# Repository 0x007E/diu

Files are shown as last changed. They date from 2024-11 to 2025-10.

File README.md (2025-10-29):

   

# `DIU` - Digital (Analog) Clock (Digitaluhr)



The `DIU` project is based on a pcb with an [ATtiny1606](#additional-information) a RTC [MCP7940](#additional-information) a USB/UART bridge [FT232RL](#additional-information) and a set of [74HC595](#additional-information) shift register. It can be used to display time and date on 84 `LEDs` that are mounted in 3 circles to the top pcb. The clock itself can be setup over UART and a terminal software ([e.g. TeraTerm](#additional-information)).

| Experience | Level |
|:---|:-----:|
| Soldering | ?% |
| Mechanical  | ?% |
| Software | ?% |

# Downloads

| Type | File | Description |
|:---:|:---:|:---|
| Schematic | [pdf](https://github.com/0x007E/diu/releases/latest/download/schematic.pdf) / [cadlab](https://cadlab.io/project/28616/main/files) | Schematic files |
| Board | [pdf](https://github.com/0x007E/diu/releases/latest/download/pcb.pdf) / [cadlab](https://cadlab.io/project/28616/main/files) | Board file |
| Drill | [pdf](https://github.com/0x007E/diu/releases/latest/download/drill.pdf) | Drill file |
| PCB | [zip](https://github.com/0x007E/diu/releases/latest/download/kicad.zip) / [tar](https://github.com/0x007E/diu/releases/latest/download/kicad.tar.gz) | KiCAD/Gerber/BoM/Drill files |
| Mechanical | [zip](https://github.com/0x007E/diu/releases/latest/download/freecad.zip) / [tar](https://github.com/0x007E/diu/releases/latest/download/freecad.tar.gz) | FreeCAD/Housing and PCB (STEP) files |
| Firmware | [zip](https://github.com/0x007E/diu/releases/latest/download/firmware.zip) / [tar](https://github.com/0x007E/diu/releases/latest/download/firmware.tar.gz) | Firmware for ATtiny1606 |
| Test-Firmware | [zip](https://github.com/0x007E/diu/releases/latest/download/test-firmware.zip) / [tar](https://github.com/0x007E/diu/releases/latest/download/test-firmware.tar.gz) | Test-Firmware for ATtiny1606 |

# Hardware

There are two parts of the hardware. The pcb and the housing of the `DIU`. The pcb is created with [KiCAD](#additional-information) and the housing with [FreeCAD](#additional-information). The software is programmed with [Microchip (Atmel) Studio](#additional-information). All files are built with `github actions` so that they are ready for a production environment. The housing is printed with a 3D-printer (`Dremel 3D40`).

## PCB

The circuit board is populated on both sides (Top, Bottom). The best way for soldering the `SMD` components is within a vapor phase soldering system and for the `THT` components with a standard soldering system. After placing and soldering the top parts, the board has to be cut off in the middle (white edge).

### Top Layer

Top Layer

### Bottom Layer

Bottom Layer

## Mechanical

The housing has a tolerance of `0.2mm` on each side of the case. So the pcb should fit perfectly in the housing. The tolerance can be modified with `FreeCAD` in the `Parameter` Spreadsheet. The corners of the circuit board need to be sanded a little.

### Assembled

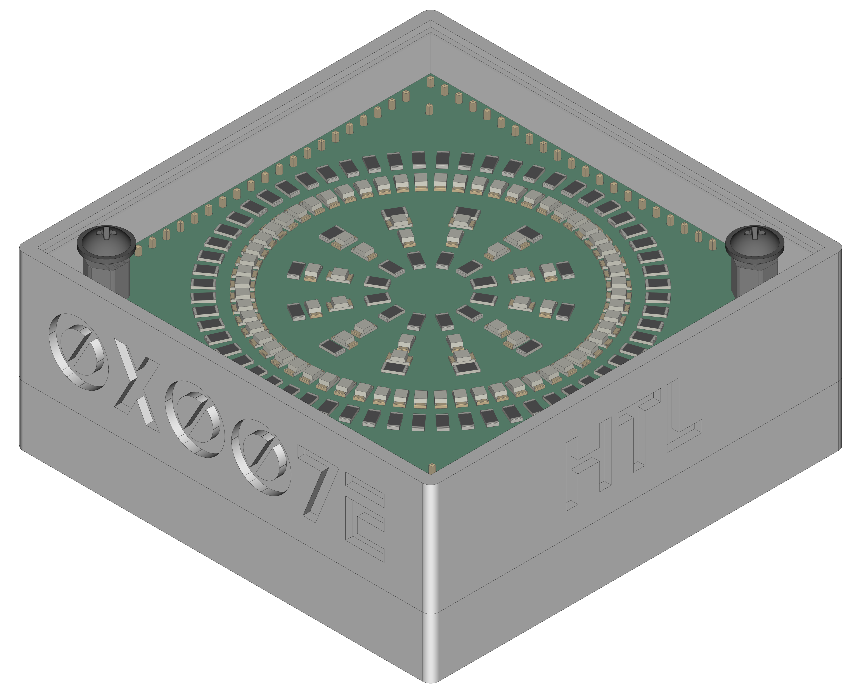
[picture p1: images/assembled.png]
Assembled


#### Exploded

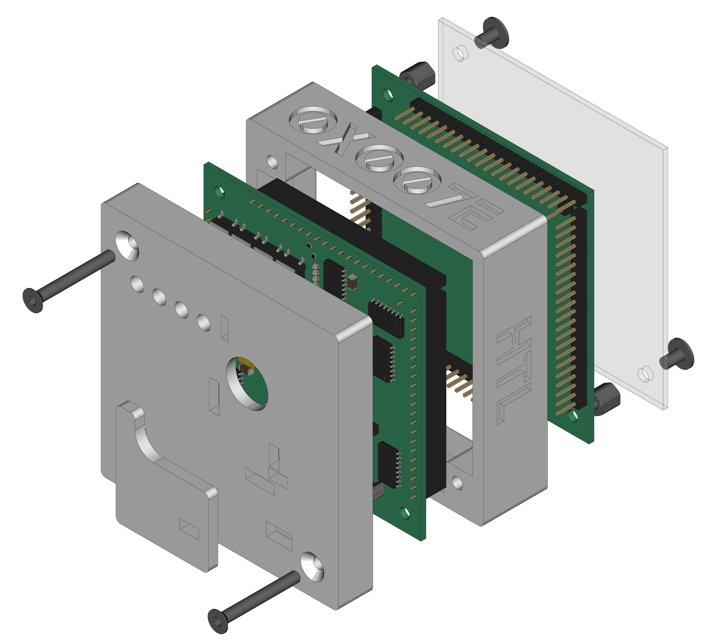
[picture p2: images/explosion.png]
Exploded


# Programming/Setup

The `DIU` can be powerd with `5V` from USB or an external source through connector `J1`. Over [UPDI](#additional-information) (`J3`) the `DIU` can be programmed with `avr-dude` or an [Microchip (Atmel) ICE](#additional-information) adapter. To setup the `DIU` it can be connected over USB to a computer and  configured with a terminal (e.g. [TeraTerm](#additional-information)) software. The firmware for the clock can be downloaded from the [download section](#downloads).

## FUSES

| Register  | Value  |
|:---:|:---:|
| `WDTCFG`  | `0x00` |
| `BODCFG`  | `0x00` |
| `OSCCFG`  | `0x02` |
| `TCD0CFG` | `0x00` |
| `SYSCFG0` | `0xF5` |
| `SYSCFG1` | `0x00` |
| `APPEND`  | `0x00` |
| `BOOTEND` | `0x00` |

> To setup `RESET` (`PA0`) it is necessary to change the `SYSCFG0`-FUSE of the `ATtiny1606`. WARNING: To reset the `PA0` pin to `UPDI` mode a `12V` impulse is necessary to program the FUSES again.

# Firmware

The firmware of the `DIU` project can be downloaded and modified with [Microchip Studio](#additional-information). The software can be found in the [`./firmware`](./firmware/) directory and is splitted into different libraries. They can be found in the [./firmware/lib`](./firmware/lib/) folder. Feel free to modify the firmware to your own needings.

## Dataflow diagram

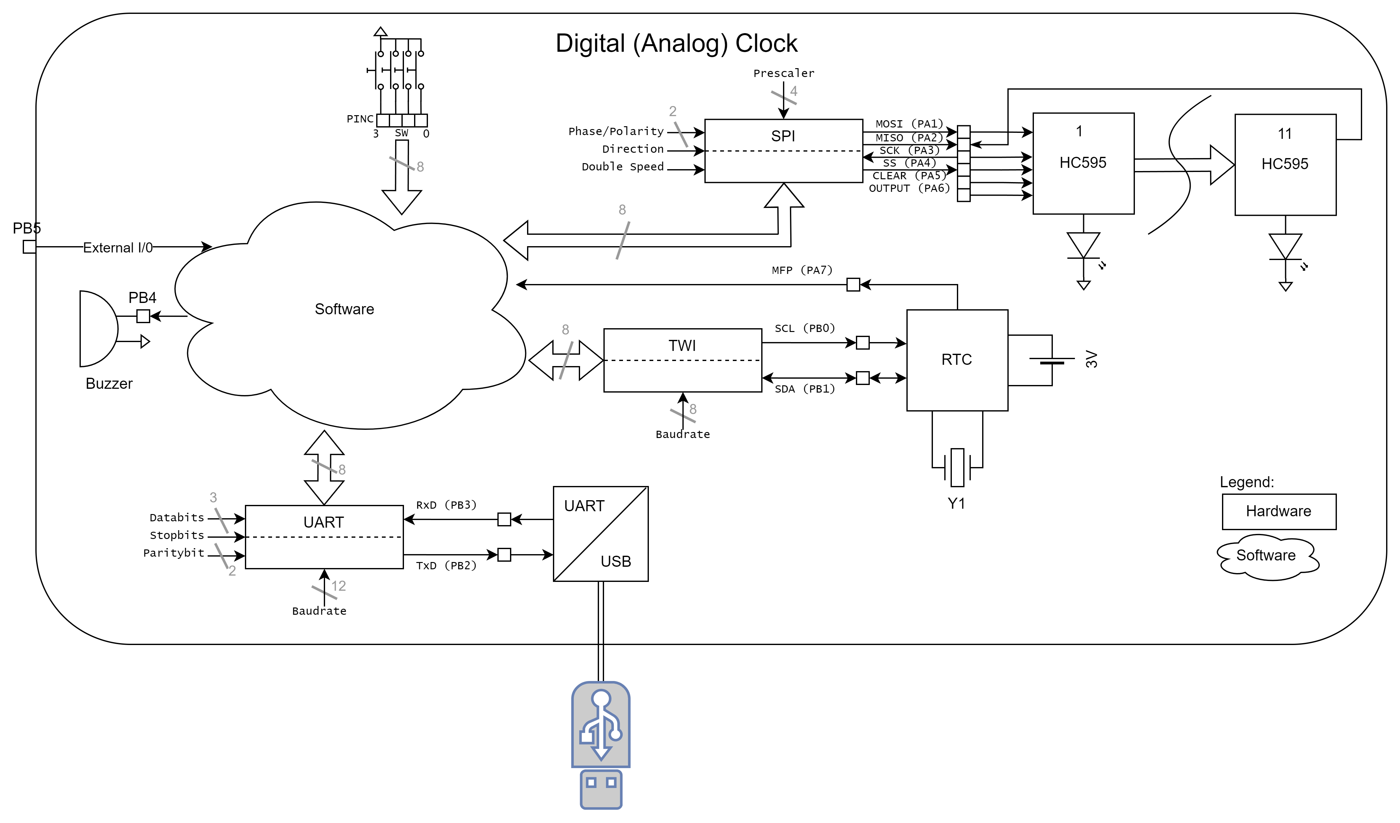
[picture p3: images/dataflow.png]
Dataflow


## UART Setup

To configure the `DIU` through UART (USB/UART bridge) a connection over USB to a computer and a terminal software (e.g. [Teraterm](#additional-information) is necessary. To start the setup the following settings need to be configured in the terminal. Then hit a key during init process in the terminal.

| Name | Value  |
|:---:|:---:|
| PORT | COM? |
| BAUD | 9600 |
| DATABITS  | 8 |
| PARITY | NONE |
| STOPBITS  | 1 |
| FLOWCTRL  | NONE |

### Connection setup

``` bash
# +--------------------------------------------------+
# |       ~------------------+                       |      +---------------------+
# |      ~  ATTINY 1606      |                       |      |                     |
# |     ~                  +-+-+                     |      | +-----------------+ |
# |    ~               VCC | 1 |          +----------+      | | TeraTerm        | |
# |      ~             PB0 | 2 |          |   U  +---+---+  | | ~~~~~~~~        | |
# |        ~           PB1 | 3 |          |   S  |  USB  |--+ | ~~~~~           | |
# |         ~    (TxD) PB2 | 4 +-----+    |   B  +---+---+  | | ~~~~~~~~~~~~    | |
# |        ~     (RxD) PB3 | 5 +--+  |    |   /      |      | |                 | |
# |       ~            GND | 6 |  |  |    |   U      |      | +-----------------+ |
# |     ~                  +-+-+  |  |    |   A      |      |                     |
# |    ~~~~~-----------------+    |  |  +-+-+ R      |      | Computer            |
# |                               |  +--+TxD| T      |      |                     |
# |  DDD   IIIIII UU  UU          +-----+RxD| +------+      +---------------------+
# |  D  D    II   UU  UU                +-+-+ |5V/3V3|
# |  D  D    II   UU  UU                  +----+-----+
# |  DDD   IIIIII  UUUU                              |
# +--------------------------------------------------+
```

### Enter configuration menu

To enter into the configuration mode it is necessary to press a `key` during startup.

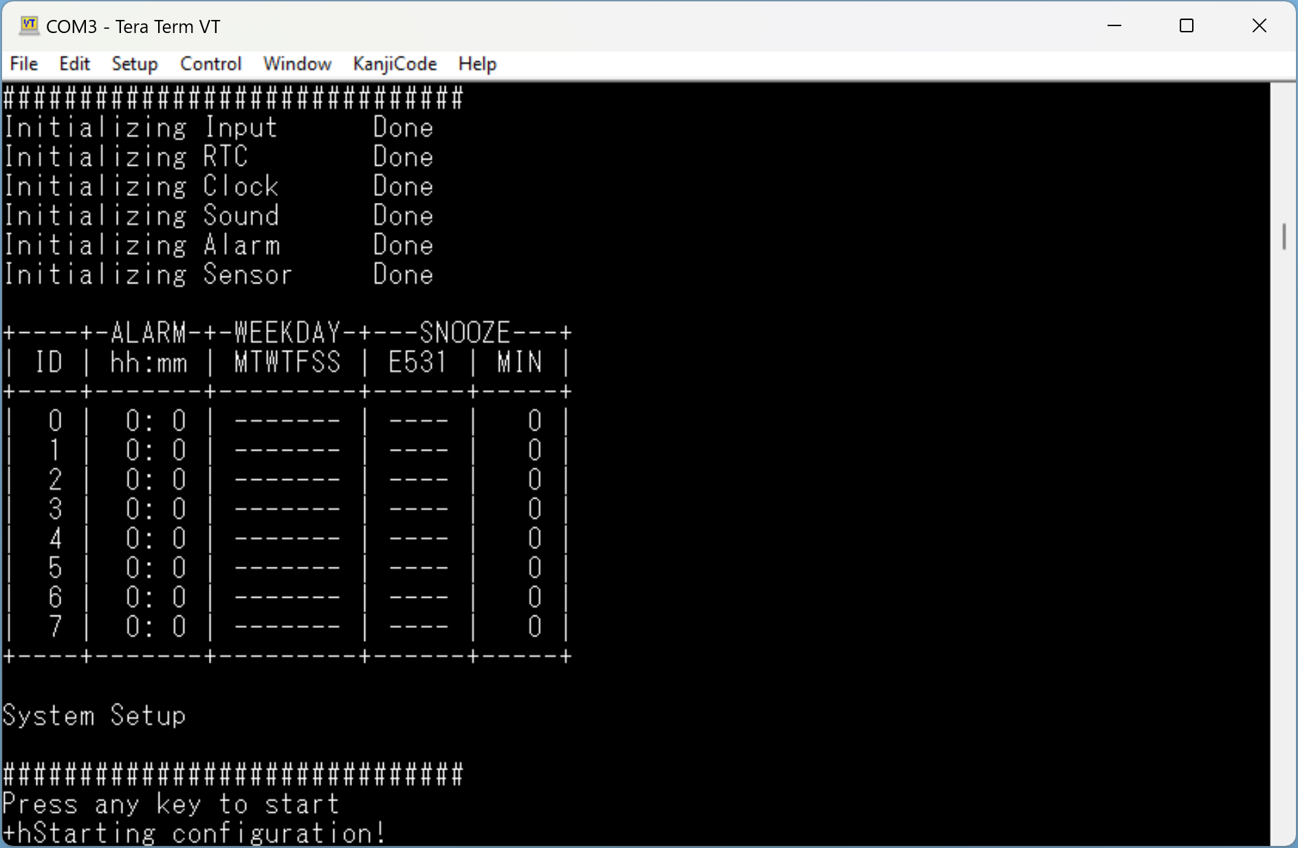
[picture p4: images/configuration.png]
Press a Key


The configuration starts and a menu to setup the `DIU` appears.

``` bash
# +------------------------------------------------+
# | System Configuration                           |
# +------------------------------------------------+
# | [1] Time and Date                              |
# | [2] Alarm                                      |
# | [3] Alarm Tone                                 |
# | [4] LED Intensity                              |
# | [5] Oscillator                                 |
# | [d] Discharge changes                          |
# | [q] Exit configuration                         |
# +------------------------------------------------+
# Input:
```

## TWI-Configuration

The `DIU` itself uses a `RTC` ([MCP7940](#additional-information)) with a power reserve (`battery`) to store the time. The `firmware` is connecte to the `RTC` over `TWI`. The twi configuration is stored in [`twi.h`](./firmware/lib/twi/twi.h) and the rtc configuration in [`mcp7940.h`](./firmware/lib/rtc/mcp7940.h) file.

### Connection between `ATtiny1606` and `MCP7940`

``` bash
# +----------------------------------------------------------------------------------------------------+
# |                               VCC VCC                                                              |
# |                                ^   ^                                                               |
# |                                |   |                                                               |
# |                             R +++ +++ R                                                            |
# |                             9 | | | | 1                                                            |
# |       ~------------------+  9 | | | | 0                                J                           |
# |      ~  ATTINY 1606      |    +++ +++ 0    +---------------------+     1    ~~~~~~                 |
# |     ~                  +-+-+   |   |     +-+-+                 +-+-+   8   ~  3   ~                |
# |    ~               VCC | X +---|---|-----+ 8 | VCC         BAT | 3 +--(X)-+   V    +------| GND    |
# |    ~         (SCL) PB0 | 0 +---+---|-----+ 6 | SCL             +-+-+       ~  0   ~                |
# |     ~        (SDA) PB1 | 1 +-------+-----+ 5 | SDA      M        |          ~~~~~~   C30           |
# |       ~            PB2 | 2 |             +-+-+          C      +-+-+                 ||            |
# |        ~           PB3 | 3 |           +-+ 5 | MFP      P   X! | 1 +----------+------||----| GND   |
# |         ~          PB4 | 4 |          /  +-+-+          7      +-+-+         ---     ||            |
# |         ~          PB5 | 5 |         /     |            9        |         +-----+                 |
# |        ~           PB6 | 6 |        /    +-+-+          4        |         |  Y1 | 32.768 kHz      |
# |       ~            GND | X +-------/-----+ 4 |          0        |         +-----+                 |
# |      ~                 +-+-+      /      +-+-+                 +-+-+         ---     ||            |
# |     ~                    |       /         |                X2 | 2 +----------+------||----| GND   |
# |     ~                  +-+-+    /          |                   +-+-+                 ||            |
# |      ~                 ~   ~   /           +---------------------+                   C31           |
# |       ~                ~   ~  /                                                                    |
# |        ~           PA7 | 7 +-+             DDD   IIIIII UU  UU                                     |
# |         ~              +-+-+               D  D    II   UU  UU                                     |
# |         ~                |                 D  D    II   UU  UU                                     |
# |        ~-----------------+                 DDD   IIIIII  UUUU                                      |
# +----------------------------------------------------------------------------------------------------+
```

### TWI Parameter

To read and save parameters in th `RTC` over `TWI` the bus is configured with the following setup:

| Parameter | Value | Description |
|:---|:---:|:---|
| Speed | 400kHz  | Bus clock speed |

> Detail can be found [here](https://en.wikipedia.org/wiki/I%C2%B2C)

### RTC-Commands

``` c
             void mcp7940_init(RTC_Mode battery);
             void mcp7940_battery(RTC_Mode mode);
             void mcp7940_oscillator(RTC_Mode mode);

    unsigned char mcp7940_oscillator_value(void);
             void mcp7940_oscillator_copy(Copy_Mode mode);

       RTC_Status mcp7940_powerfail_status(void);
       RTC_Status mcp7940_oscillator_status(void);

      const char* mcp7940_weekday_string(unsigned char day);
    
    unsigned char mcp7940_hour(RTC_Data data);
    unsigned char mcp7940_minute(RTC_Data data);
    unsigned char mcp7940_second(void);

    unsigned char mcp7940_weekday(RTC_Data data);
    unsigned char mcp7940_day(RTC_Data data);
    unsigned char mcp7940_month(RTC_Data data);
    unsigned char mcp7940_year(void);
    unsigned char mcp7940_leapyear(void);

       RTC_Status mcp7940_setweekday(unsigned char weekday);
       RTC_Status mcp7940_settime(unsigned char hour, unsigned char minute, unsigned char second);
       RTC_Status mcp7940_setdate(unsigned char day, unsigned char month, unsigned char year);
       RTC_Status mcp7940_setoscillator(unsigned char trim);
```

## SPI-Configuration

The `firmware` itself is driving the LEDs over `SPI` through eleven [74HC595](#additional-information) shift registers. The spi configuration is stored in the [`clock.h`](./firmware/lib/clock/clock.h) and [`spi.h`](./firmware/lib/spi/spi.h) files.

### Connection between `ATtiny1606` and `74HC595`

``` bash
# +------------------------------------------------------------------------------------------------------+
# |                                     +----------------------------... ~ ...------------------------+  |
# |       ~------------------+         /            START(1)            ~             END(11)         |  | 
# |      ~  ATTINY 1606      |        /        +---------------+       ~         +---------------+    |  |
# |     ~                  +-+-+     /       +-+-+  74HC595  +-+-+    ~        +-+-+  74HC595  +-+-+  |  |
# |    ~               VCC | X +----/--------+ 16|    VCC    |16 |-.. ~ ....---+ 16|    VCC    |16 |  |  |
# |    ~               PA0 | 0 |   /         +---+           +-+-+     ~       +---+           +-+-+  |  |
# |     ~       (MOSI) PA1 | 1 +--/----------+ 14| SER    QH | 9 |--... ~ ...--+ 14| SER    QH | 9 +--+  |
# |       ~     (MISO) PA2 | 2 +-+           +---+           +-+-+       ~     +---+           +-+-+     |
# |        ~     (SCK) PA3 | 3 +-------------+ 11|   SRCLK   |11 |----... ~ ..-+ 11|   SRCLK   |11 |     |
# |         ~     (SS) PA4 | 4 +-------------+ 12|    RCLK   |12 |----... ~ ..-+ 12|    RCLK   |12 |     |
# |         ~  (CLEAR) PA5 | 5 +-------------+ 10|   SRCLR   |10 |---... ~ ...-+ 10|   SRCLR   |10 |     |
# |        ~  (OUTPUT) PA6 | 6 +-------------+ 13|     OE    |13 |--... ~ ...--+ 13|     OE    |13 |     |
# |       ~            GND | X +-------------+ 8 |    GND    | 8 |-... ~ ...---+ 8 |    GND    | 8 |     |
# |     ~                  +-+-+             +-+-+           +-+-+    ~        +-+-+           +-+-+     |
# |    ~~~~~-----------------+                 +--+~~~~~~~~~+--+      ~          +--+~~~~~~~~~+--+       |
# |                                               |         |          ~            |         |          |
# |  DDD   IIIIII UU  UU                         ---  LED  ---          ~          ---  LED  ---         |   
# |  D  D    II   UU  UU                         \ /       \ /           ~         \ /       \ /         |
# |  D  D    II   UU  UU                          |         |             ~         |         |          |
# |  DDD   IIIIII  UUUU                           |         |             ~         |         |          |
# +------------------------------------------------------------------------------------------------------+
```

### SPI Parameter

To control the LEDs through the shift registers over `SPI` the bus is configured with the following setup:

| Parameter | Value | Description |
|:---|:---:|:---|
| Clock | F_CPU/4 | Bus clock speed is system speed divied by 4 |
| Direction | MSB | MSB needs to be transmitted first |
| Polarity  | Rising  | Polarity of clock is rising `_/` |
| Phase | Rising  | Data is valid when clock is rising `_/` |

> Detail can be found [here](https://de.wikipedia.org/wiki/Serial_Peripheral_Interface)

### SPI Frame

``` bash

# SPI display transmission
# _                                                SS                                                   _
#  \__________________________________________________~~~______________________________________________/
#                                                 SCK   
#     __    __    __    __    __    __    __    __       __    __    __    __    __    __    __    __    
# ___/1 \__/2 \__/3 \__/4 \__/5 \__/6 \__/7 \__/8 \__~~~/81\__/82\__/83\__/84\__/85\__/86\__/87\__/88\___
#                                                 MOSI
#    __    __    __    __    __    __    __    __       __    __    __    __    __    __    __    __
# __/H \__/O \__/U \__/R \__/  \__/  \__/  \__/  \__~~~/M \__/I \__/N \__/  \__/L3\__/L2\__/L1\__/L0\____
#   \__/  \__/  \__/  \__/  \__/  \__/  \__/  \__/     \__/  \__/  \__/  \__/  \__/  \__/  \__/  \__/
#    [7                   :                    0]    [7                   :                    0]
#
# L[3:0] ... LEDs on the backside of the pcb for signaling
```

### Clock-Commands

``` c
           void clock_init(void);
           void clock_output(CLOCK_Status status);
           void clock_clear(void);
   unsigned int clock_intensity(void);
    CLOCK_Error clock_setintensity(unsigned int intensity);
           void clock_copy_intensity(Copy_Mode mode);
    CLOCK_Error clock_settime(unsigned char hour, unsigned char minute, unsigned char second, CLOCK_Status_LED status);
    CLOCK_Error clock_setdate(unsigned char day, unsigned char month, CLOCK_Status_LED status);
           void clock_setdata(unsigned long data24, unsigned long long data60, CLOCK_Status_LED status);
           void clock_saveintensity(void);
```

# Additional Information

| Type | Link | Description |
|:---:|:---:|:---|
| ATtiny1606 | [pdf](http://ww1.microchip.com/downloads/en/DeviceDoc/ATtiny806_1606_Data_Sheet_40002029A.pdf) | ATtiny microcontroller |
| MPC7940 | [pdf](https://ww1.microchip.com/downloads/aemDocuments/documents/MPD/ProductDocuments/DataSheets/MCP7940N-Battery-Backed-I2C-RTCC-with-SRAM-20005010J.pdf) | Battery-Backed I2C Real-Time Clock/Calendar with SRAM |
| FT232RL | [pdf](https://ftdichip.com/wp-content/uploads/2020/08/DS_FT232R.pdf) | USB Full Speed to Serial UART IC, Includes Oscillator and EEPROM |
| 74HC595 | [pdf](https://www.ti.com/lit/ds/symlink/sn74hc595.pdf?) | 8-Bit Shift Registers With 3-State Output Registers |
| Atmel ICE | [pdf](https://ww1.microchip.com/downloads/en/DeviceDoc/Atmel-ICE_UserGuide.pdf) | Atmel ICE datasheet |
| UPDI | [web](https://github.com/0x007e/updi) | UPDI-Adapter with AVR-Dude |
| Microchip Studio | [web](https://www.microchip.com/en-us/tools-resources/develop/microchip-studio) | Download page for Microchip Studio |
| KiCAD | [web](https://www.kicad.org/) | KiCAD project page |
| FreeCAD | [web](https://www.freecad.org/) | FreeCAD project page |
| TeraTerm | [web](https://github.com/TeraTermProject/teraterm/releases/download/v5.3/teraterm-5.3.zip) | Terminal software for UART |

---

R. GAECHTER

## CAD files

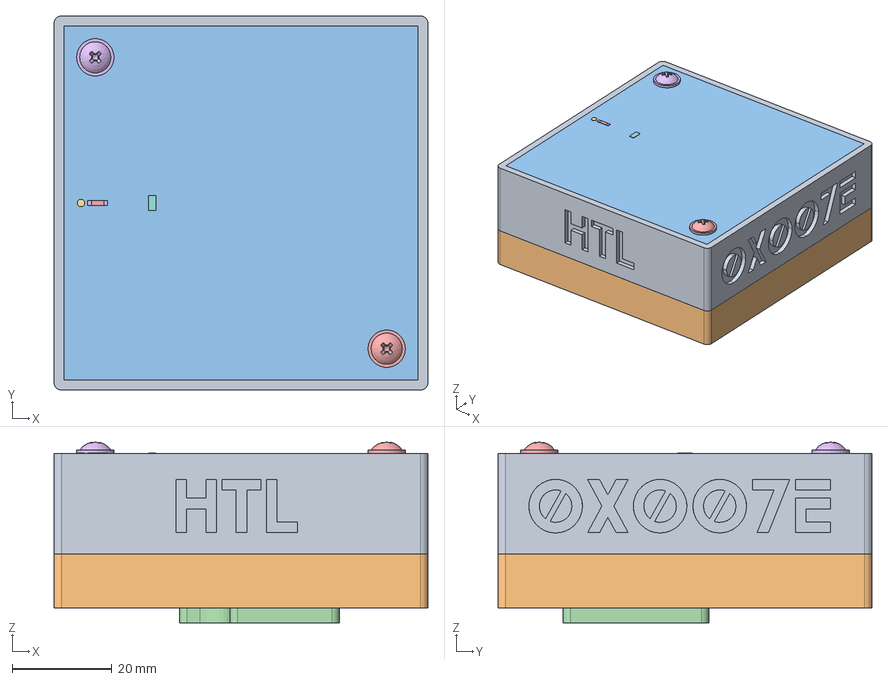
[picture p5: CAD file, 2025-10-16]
mechanical/housing.FCStd
75.0 x 75.0 x 36.2 mm
Pcb_c823
R13_R_1206_3216Metric_34334d02fc96
R44_R_1206_3216Metric_737dba1be889
R37_R_1206_3216Metric_834d129e5901
R79_R_1206_3216Metric_35fc0c29ad5f
D65_LED_1206_3216Metric_9e7b87f42873
D2_LED_1206_3216Metric_fdbedf3a3e9b
R43_R_1206_3216Metric_719967f5957d
D27_LED_1206_3216Metric_a198e4acb3d3
R38_R_1206_3216Metric_523115ea511a
D13_LED_1206_3216Metric_455e7213887b
D25_LED_1206_3216Metric_76b92dfb3f17
R21_R_1206_3216Metric_e90a38714b10
R19_R_1206_3216Metric_193c421c075a
R6_R_1206_3216Metric_35c49ca2423b
R8_R_1206_3216Metric_42ef1dca9180
D66_LED_1206_3216Metric_eba1fa753a25
R39_R_1206_3216Metric_491c422fc7de
R41_R_1206_3216Metric_edfd6f096ba8
R4_R_1206_3216Metric_de8c2cc0fb6b
R31_R_1206_3216Metric_0a769164ac2c
D45_LED_1206_3216Metric_362e80296509
R74_R_1206_3216Metric_666f53dd8cfe
D70_LED_1206_3216Metric_ddec581c3f35
D6_LED_1206_3216Metric_155b99a387b2
D53_LED_1206_3216Metric_5ce0a0b5670f
D7_LED_1206_3216Metric_7674877d52a3
R73_R_1206_3216Metric_1ad9b93e3157
R3_R_1206_3216Metric_c9d2bb2283cd
R22_R_1206_3216Metric_08c140825ab3
D68_LED_1206_3216Metric_9cb3968d07ed
D54_LED_1206_3216Metric_7693143a76bc
R55_R_1206_3216Metric_1144fcfe9ccc
R17_R_1206_3216Metric_2963d2833a7b
R7_R_1206_3216Metric_cc86824d3ca2
D71_LED_1206_3216Metric_bd39b554a851
R25_R_1206_3216Metric_359f7886d384
D23_LED_1206_3216Metric_06078b84c13d
R24_R_1206_3216Metric_ef7290cbcc05
D76_LED_1206_3216Metric_c139421844a5
R34_R_1206_3216Metric_53b750e92204
D81_LED_1206_3216Metric_de4fcd1b8e00
D39_LED_1206_3216Metric_e95fa8479d74
R60_R_1206_3216Metric_c6abe7adbdfb
D47_LED_1206_3216Metric_cf422c87c905
D55_LED_1206_3216Metric_532611b90687
D26_LED_1206_3216Metric_bbf42a41a116
D33_LED_1206_3216Metric_cf7bbe964a9d
R40_R_1206_3216Metric_b02a59e2a5f4
R62_R_1206_3216Metric_35f68ac2fdf5
R51_R_1206_3216Metric_f9cba5a0bb78
R57_R_1206_3216Metric_640c153382fb
D31_LED_1206_3216Metric_bdbaa0677122
D41_LED_1206_3216Metric_e36032ae5237
R53_R_1206_3216Metric_90ab64d636a1
D35_LED_1206_3216Metric_ba6542c84515
R28_R_1206_3216Metric_8ded0d01a810
R56_R_1206_3216Metric_063fd8314cb7
D29_LED_1206_3216Metric_22e97f871525
D22_LED_1206_3216Metric_b11cf042c014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

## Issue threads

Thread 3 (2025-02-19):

Save oscillator value for RTC in EEPROM

0x007E, 2025-02-19:
The oscillator value should be stored in the EEPROM of the MCU (ATTiny) so that it can be reloaded into the RTC after a battery change. At every startup of the RTC it should be checked an reloaded if the value between the EEPROM and the RTC differs.

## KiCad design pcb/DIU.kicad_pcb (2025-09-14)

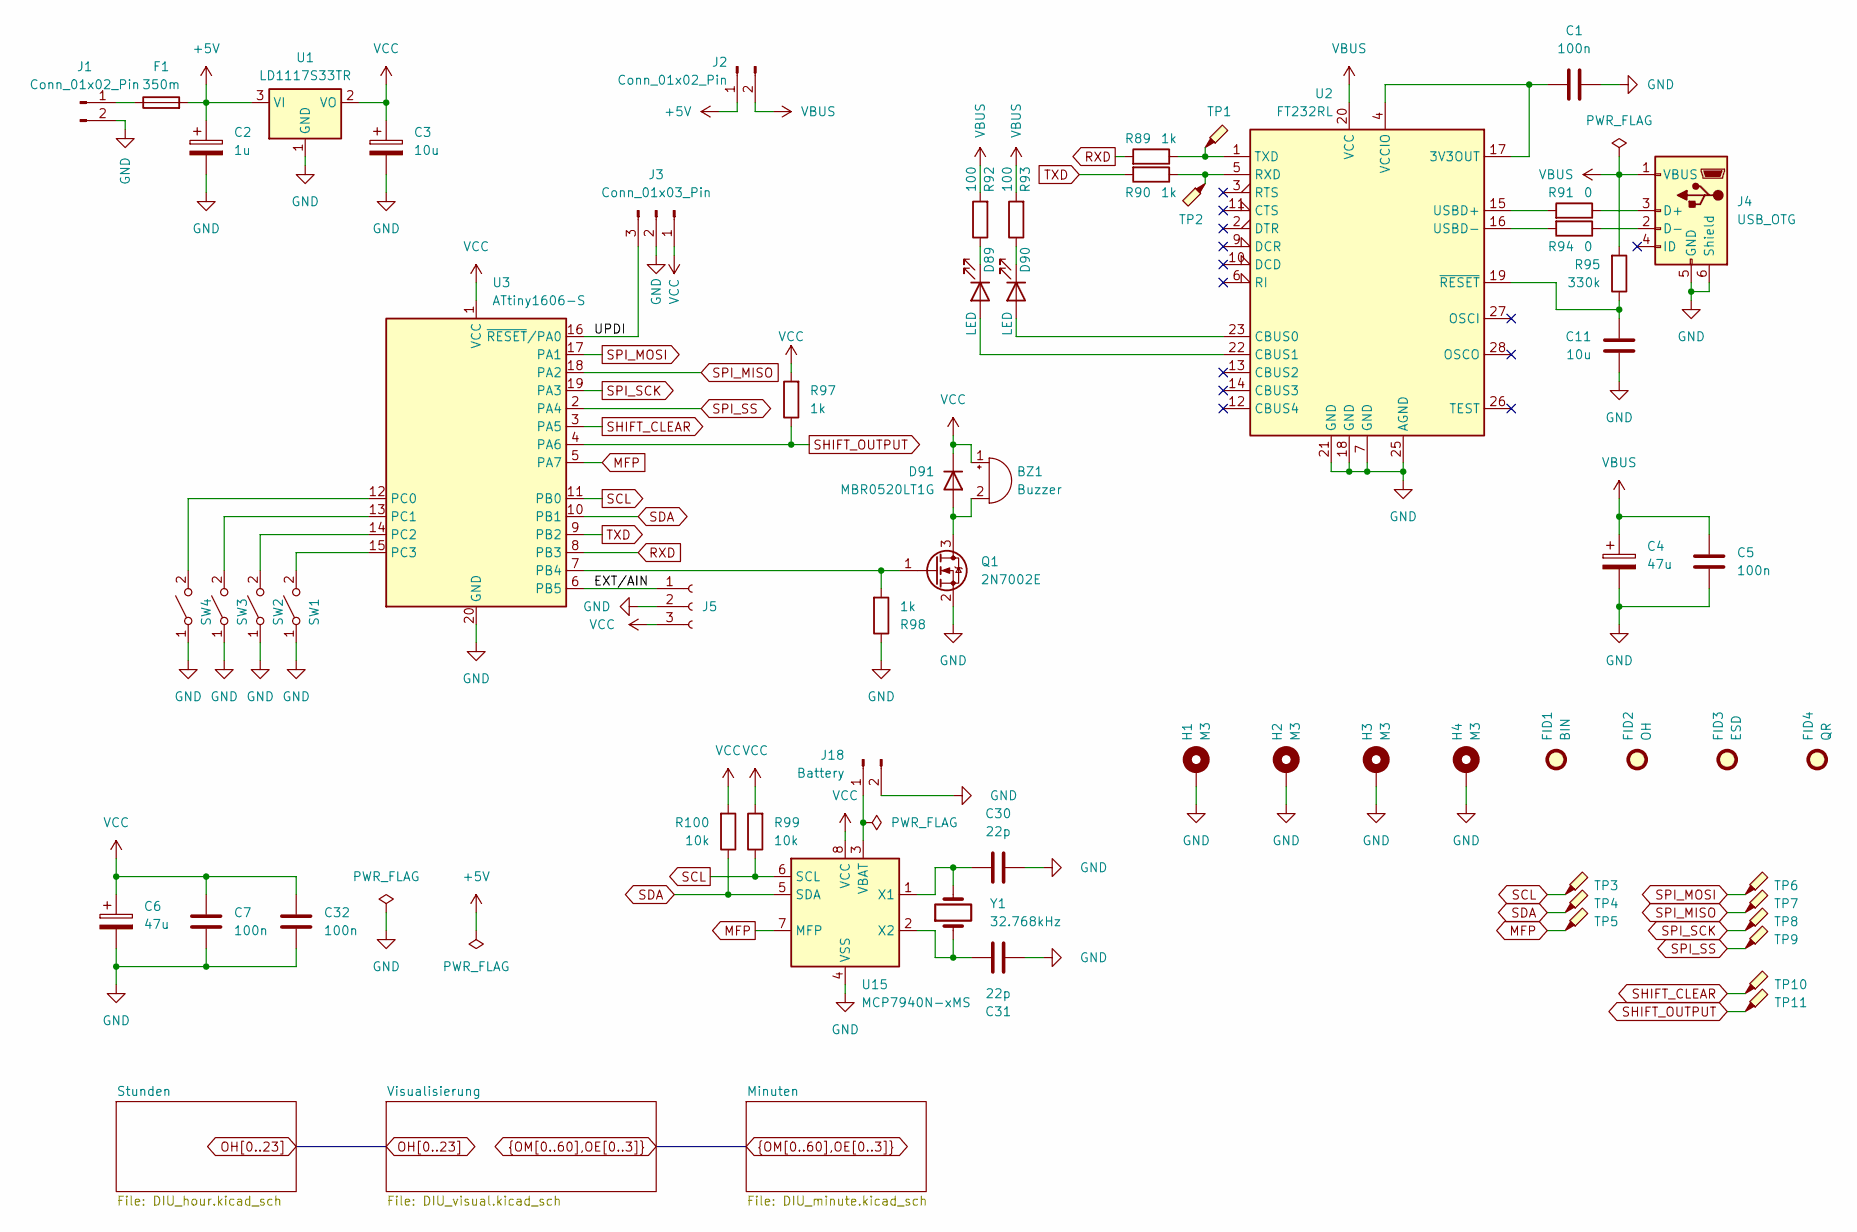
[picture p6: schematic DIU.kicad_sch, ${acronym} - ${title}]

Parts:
BZ1: Buzzer; MagneticBuzzer_ProSignal_ABT-410-RC
C1, C32: 100n; C_0603_1608Metric
C2: 1u; CP_EIA-3528-21_Kemet-B
C3: 10u; CP_EIA-6032-28_Kemet-C
C4, C6: 47u; CP_EIA-6032-15_Kemet-U
C5, C7: 100n; C_1206_3216Metric
C11: 10u; C_0603_1608Metric
C30, C31: 22p; C_0603_1608Metric
D89, D90: LED; LED_0603_1608Metric
D91: MBR0520LT1G; D_SOD-123
F1: 350m; Fuse_1206_3216Metric_Pad1.42x1.75mm_HandSolder
FID1: BIN; WEEE-Logo_4.2x6mm_SilkScreen
FID2: OH; OSHW-Logo2_7.3x6mm_SilkScreen
FID3: ESD; ESD-Logo_6.6x6mm_SilkScreen
FID4: QR; QR_0x007e
H1, H2, H3, H4: M3; MountingHole_3.2mm_M3_DIN965_Pad
J1, J2: Conn_01x02_Pin; PinHeader_1x02_P2.54mm_Vertical
J3: Conn_01x03_Pin; PinHeader_1x03_P2.54mm_Vertical
J4: USB_OTG; USB_Mini-B_Tensility_54-00023_Vertical
J5: Conn_01x03_Socket; PinSocket_1x03_P2.54mm_Vertical
J18: Battery; BatteryHolder_LINX_BAT-HLD-012-SMT
Q1: 2N7002E; SOT-23
R89, R90: 1k; R_0603_1608Metric
R91, R94: 0; R_0603_1608Metric
R92, R93: 100; R_0603_1608Metric
R95: 330k; R_0603_1608Metric
R97, R98: 1k; R_1206_3216Metric
R99, R100: 10k; R_0603_1608Metric
SW1, SW2, SW3, SW4: SW_SPST; SW_SPST_PTS645
TP1, TP2, TP3, TP4, TP5, TP6, TP7, TP8, TP9, TP10, TP11: TestPoint_Probe; TestPoint_Pad_D1.0mm
U1: LD1117S33TR; TO-263-2
U2: FT232RL; SSOP-28_5.3x10.2mm_P0.65mm
U3: ATtiny1606-S; SOIC-20W_7.5x12.8mm_P1.27mm
U15: MCP7940N-xMS; SOIC-8_3.9x4.9mm_P1.27mm
Y1: 32.768kHz; Crystal_SMD_3215-2Pin_3.2x1.5mm

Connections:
+5V: C2.1, F1.2, J2.1, U1.3 (VI)
/EXT/AIN: J5.1, U3.6 (PB5)
/UPDI: J3.3, U3.16 (~RESET/PA0)
GND: C1.2, C2.2, C3.2, C4.2, C5.2, C6.2, C7.2, C11.1, C30.2, C31.2, C32.2, H1.1, H2.1, H3.1, H4.1, J1.2, J3.2, J4.5 (GND), J4.6 (Shield), J5.2, J18.2, Q1.2 (S), R98.1, SW1.1 (A), SW2.1 (A), SW3.1 (A), SW4.1 (A), U1.1 (GND), U2.7 (GND), U2.18 (GND), U2.21 (GND), U2.25 (AGND), U3.20 (GND), U15.4 (VSS); also elsewhere on the board
MFP: TP5.1, U3.5 (PA7), U15.7 (MFP)
unnamed: BZ1.2 (-), D91.2 (A), Q1.3 (D)
unnamed: D89.2 (A), U2.22 (CBUS1)
unnamed: D89.1 (K), R92.1
unnamed: D90.2 (A), U2.23 (CBUS0)
unnamed: D90.1 (K), R93.1
unnamed: F1.1, J1.1
unnamed: J4.3 (D+), R91.1
unnamed: J4.2 (D-), R94.1
unnamed: J18.1, U15.3 (VBAT)
unnamed: Q1.1 (G), R98.2, U3.7 (PB4)
unnamed: SW1.2 (B), U3.15 (PC3)
unnamed: SW2.2 (B), U3.14 (PC2)
unnamed: SW3.2 (B), U3.13 (PC1)
unnamed: SW4.2 (B), U3.12 (PC0)
unnamed: C1.1, U2.4 (VCCIO), U2.17 (3V3OUT)
unnamed: R90.1, TP2.1, U2.5 (RXD)
unnamed: R89.1, TP1.1, U2.1 (TXD)
unnamed: R91.2, U2.15 (USBD+)
unnamed: R94.2, U2.16 (USBD-)
unnamed: C11.2, R95.1, U2.19 (~RESET)
unnamed: C30.1, U15.1 (X1), Y1.2
unnamed: C31.1, U15.2 (X2), Y1.1
RXD: R89.2, U3.8 (PB3)
SCL: R99.1, TP3.1, U3.11 (PB0), U15.6 (SCL)
SDA: R100.1, TP4.1, U3.10 (PB1), U15.5 (SDA)
SHIFT_CLEAR: TP10.1, U3.3 (PA5); also elsewhere on the board
SHIFT_OUTPUT: R97.1, TP11.1, U3.4 (PA6); also elsewhere on the board
SPI_MISO: TP7.1, U3.18 (PA2); also elsewhere on the board
SPI_MOSI: TP6.1, U3.17 (PA1); also elsewhere on the board
SPI_SCK: TP8.1, U3.19 (PA3); also elsewhere on the board
SPI_SS: TP9.1, U3.2 (PA4); also elsewhere on the board
TXD: R90.2, U3.9 (PB2)
VBUS: C4.1, C5.1, J2.2, J4.1 (VBUS), R92.2, R93.2, R95.2, U2.20 (VCC)
VCC: BZ1.1 (+), C3.1, C6.1, C7.1, C32.1, D91.1 (K), J3.1, J5.3, R97.2, R99.2, R100.2, U1.2 (VO), U3.1 (VCC), U15.8 (VCC); also elsewhere on the board

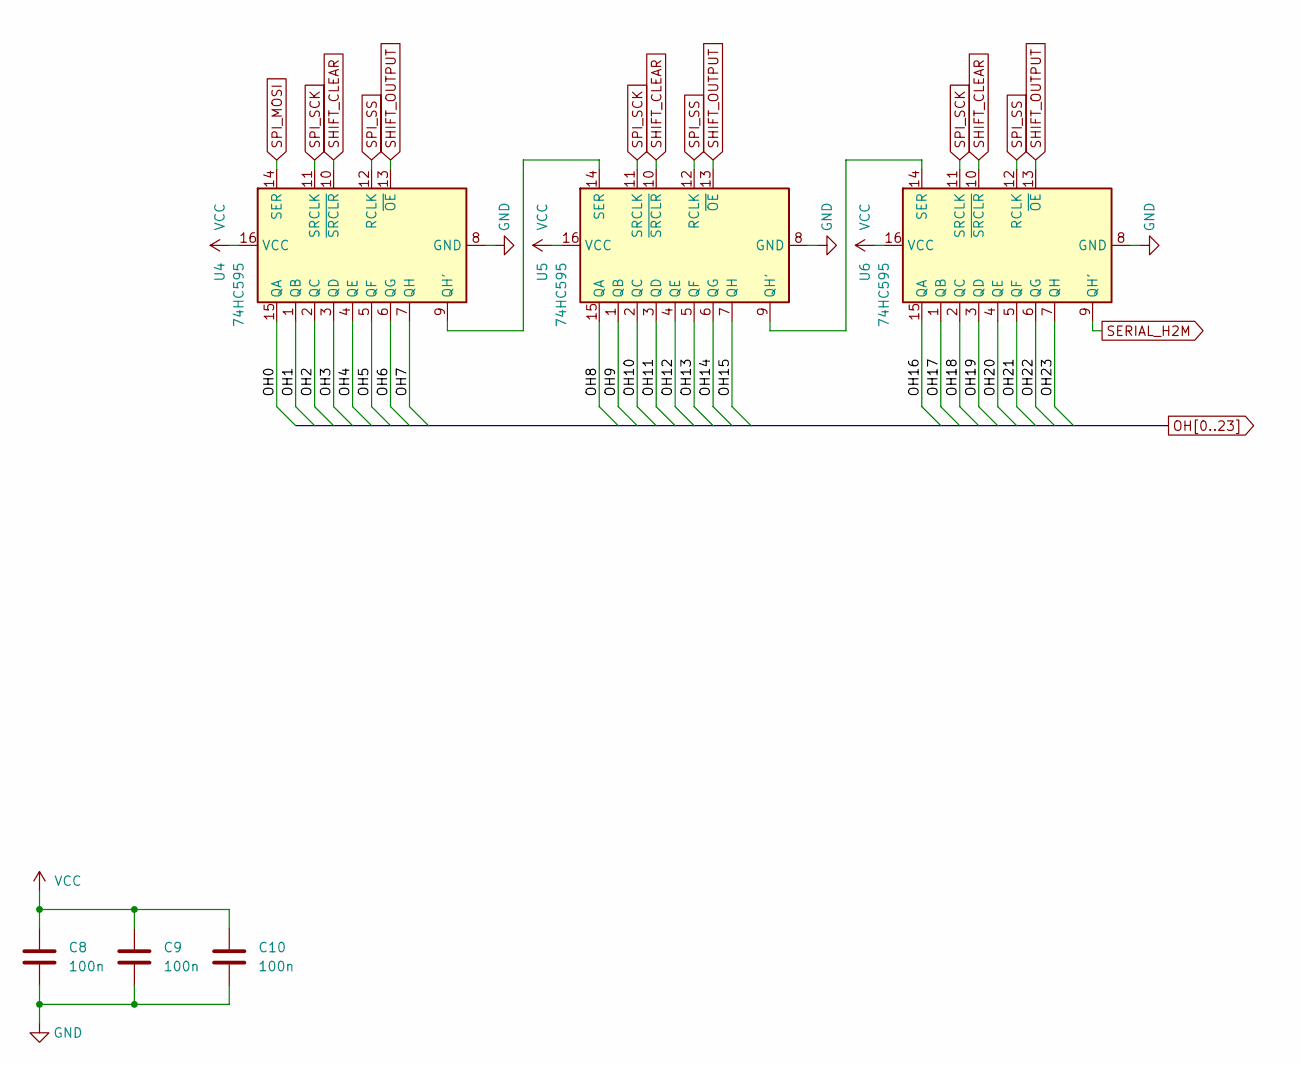
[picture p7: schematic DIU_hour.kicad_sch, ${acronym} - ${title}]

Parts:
C8, C9, C10: 100n; C_1206_3216Metric
U4, U5, U6: 74HC595; SOIC-16W_5.3x10.2mm_P1.27mm

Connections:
GND: C8.2, C9.2, C10.2, U4.8 (GND), U5.8 (GND), U6.8 (GND); also elsewhere on the board
unnamed: U4.9 (QH'), U5.14 (SER)
unnamed: U5.9 (QH'), U6.14 (SER)
OH0: U4.15 (QA); also elsewhere on the board
OH1: U4.1 (QB); also elsewhere on the board
OH2: U4.2 (QC); also elsewhere on the board
OH3: U4.3 (QD); also elsewhere on the board
OH4: U4.4 (QE); also elsewhere on the board
OH5: U4.5 (QF); also elsewhere on the board
OH6: U4.6 (QG); also elsewhere on the board
OH7: U4.7 (QH); also elsewhere on the board
OH8: U5.15 (QA); also elsewhere on the board
OH9: U5.1 (QB); also elsewhere on the board
OH10: U5.2 (QC); also elsewhere on the board
OH11: U5.3 (QD); also elsewhere on the board
OH12: U5.4 (QE); also elsewhere on the board
OH13: U5.5 (QF); also elsewhere on the board
OH14: U5.6 (QG); also elsewhere on the board
OH15: U5.7 (QH); also elsewhere on the board
OH16: U6.15 (QA); also elsewhere on the board
OH17: U6.1 (QB); also elsewhere on the board
OH18: U6.2 (QC); also elsewhere on the board
OH19: U6.3 (QD); also elsewhere on the board
OH20: U6.4 (QE); also elsewhere on the board
OH21: U6.5 (QF); also elsewhere on the board
OH22: U6.6 (QG); also elsewhere on the board
OH23: U6.7 (QH); also elsewhere on the board
SERIAL_H2M: U6.9 (QH'); also elsewhere on the board
SHIFT_CLEAR: U4.10 (~SRCLR), U5.10 (~SRCLR), U6.10 (~SRCLR); also elsewhere on the board
SHIFT_OUTPUT: U4.13 (~OE), U5.13 (~OE), U6.13 (~OE); also elsewhere on the board
SPI_MOSI: U4.14 (SER); also elsewhere on the board
SPI_SCK: U4.11 (SRCLK), U5.11 (SRCLK), U6.11 (SRCLK); also elsewhere on the board
SPI_SS: U4.12 (RCLK), U5.12 (RCLK), U6.12 (RCLK); also elsewhere on the board
VCC: C8.1, C9.1, C10.1, U4.16 (VCC), U5.16 (VCC), U6.16 (VCC); also elsewhere on the board

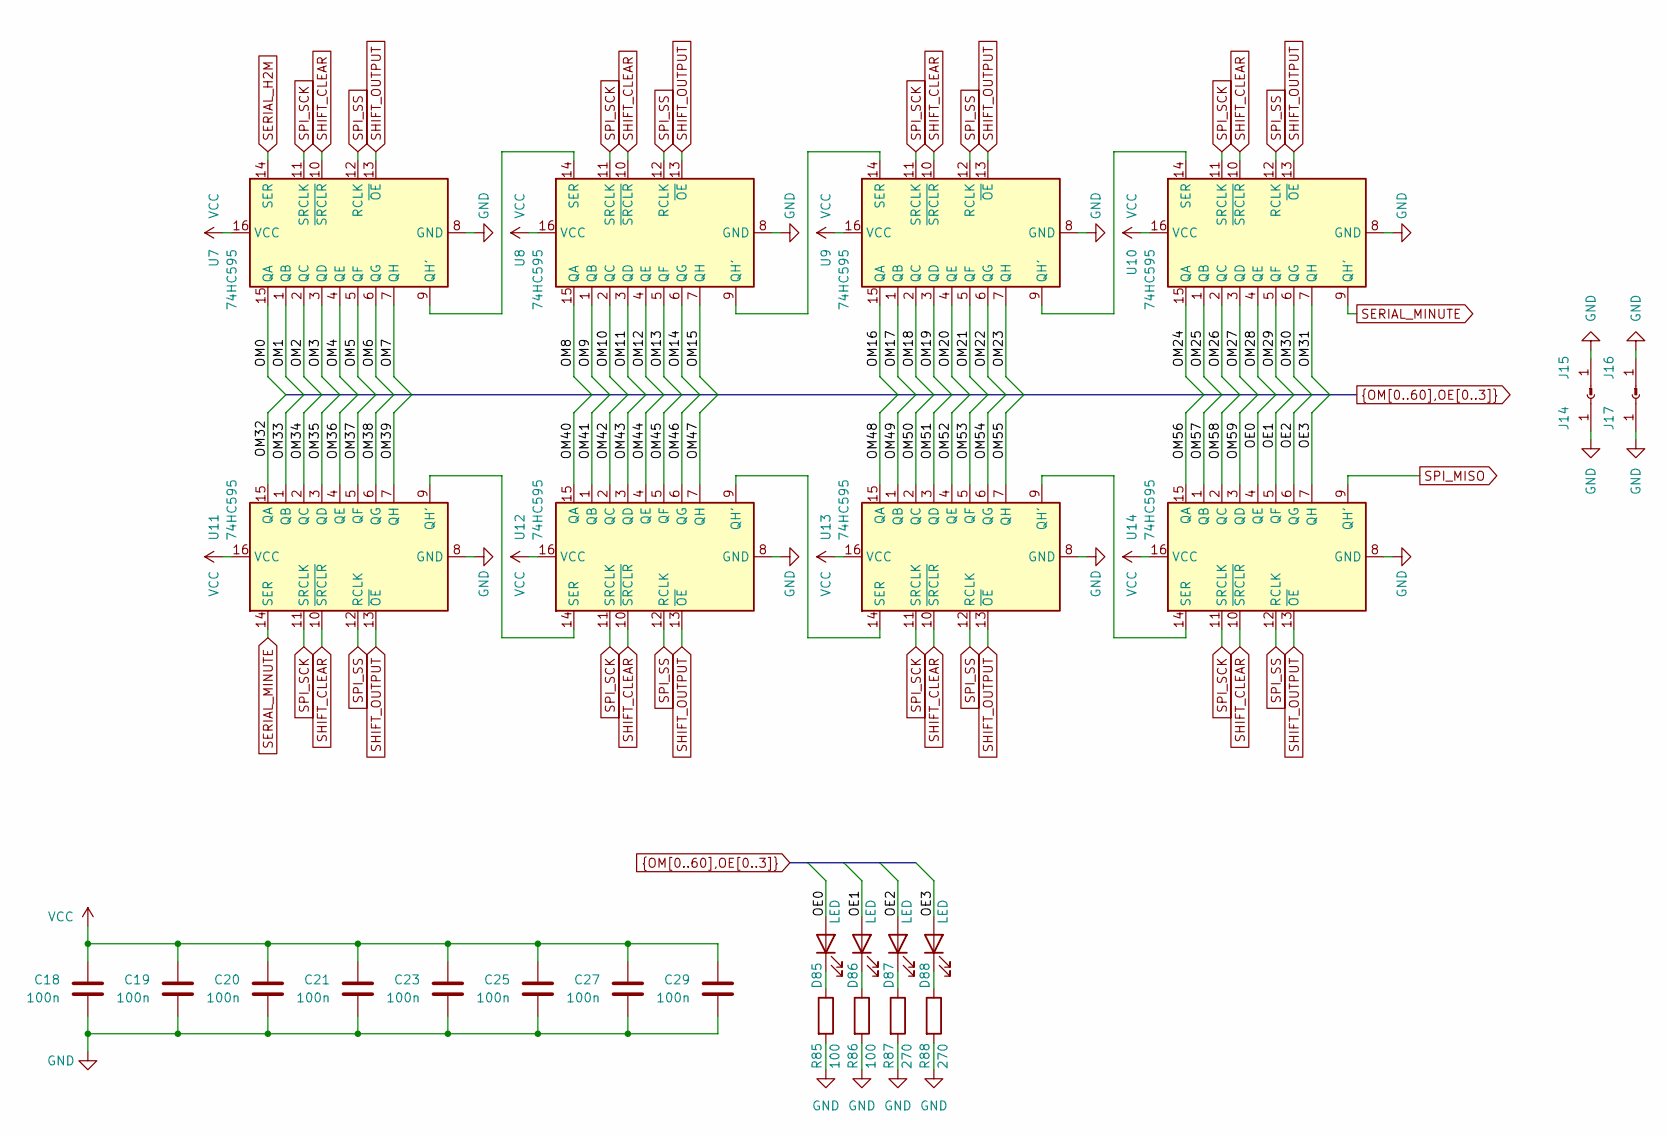
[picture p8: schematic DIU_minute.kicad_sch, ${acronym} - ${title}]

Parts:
C18, C19, C20, C21, C23, C25, C27, C29: 100n; C_1206_3216Metric
D85, D86, D87, D88: LED; LED_0603_1608Metric
J14, J17: Conn_01x01_Socket; PinSocket_1x01_P2.54mm_Vertical
J15, J16: Conn_01x01_Pin; PinHeader_1x01_P2.54mm_Vertical
R85, R86: 100; R_0603_1608Metric
R87, R88: 270; R_0603_1608Metric
U7, U8, U9, U10, U11, U12, U13, U14: 74HC595; SOIC-16W_5.3x10.2mm_P1.27mm

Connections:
GND: C18.2, C19.2, C20.2, C21.2, C23.2, C25.2, C27.2, C29.2, J14.1, J15.1, J16.1, J17.1, R85.2, R86.2, R87.2, R88.2, U7.8 (GND), U8.8 (GND), U9.8 (GND), U10.8 (GND), U11.8 (GND), U12.8 (GND), U13.8 (GND), U14.8 (GND); also elsewhere on the board
unnamed: D85.1 (K), R85.1
unnamed: D86.1 (K), R86.1
unnamed: D87.1 (K), R87.1
unnamed: D88.1 (K), R88.1
unnamed: U7.9 (QH'), U8.14 (SER)
unnamed: U8.9 (QH'), U9.14 (SER)
unnamed: U9.9 (QH'), U10.14 (SER)
unnamed: U11.9 (QH'), U12.14 (SER)
unnamed: U12.9 (QH'), U13.14 (SER)
unnamed: U13.9 (QH'), U14.14 (SER)
OE0: D85.2 (A), U14.4 (QE)
OE1: D86.2 (A), U14.5 (QF)
OE2: D87.2 (A), U14.6 (QG)
OE3: D88.2 (A), U14.7 (QH)
OM0: U7.15 (QA); also elsewhere on the board
OM1: U7.1 (QB); also elsewhere on the board
OM2: U7.2 (QC); also elsewhere on the board
OM3: U7.3 (QD); also elsewhere on the board
OM4: U7.4 (QE); also elsewhere on the board
OM5: U7.5 (QF); also elsewhere on the board
OM6: U7.6 (QG); also elsewhere on the board
OM7: U7.7 (QH); also elsewhere on the board
OM8: U8.15 (QA); also elsewhere on the board
OM9: U8.1 (QB); also elsewhere on the board
OM10: U8.2 (QC); also elsewhere on the board
OM11: U8.3 (QD); also elsewhere on the board
OM12: U8.4 (QE); also elsewhere on the board
OM13: U8.5 (QF); also elsewhere on the board
OM14: U8.6 (QG); also elsewhere on the board
OM15: U8.7 (QH); also elsewhere on the board
OM16: U9.15 (QA); also elsewhere on the board
OM17: U9.1 (QB); also elsewhere on the board
OM18: U9.2 (QC); also elsewhere on the board
OM19: U9.3 (QD); also elsewhere on the board
OM20: U9.4 (QE); also elsewhere on the board
OM21: U9.5 (QF); also elsewhere on the board
OM22: U9.6 (QG); also elsewhere on the board
OM23: U9.7 (QH); also elsewhere on the board
OM24: U10.15 (QA); also elsewhere on the board
OM25: U10.1 (QB); also elsewhere on the board
OM26: U10.2 (QC); also elsewhere on the board
OM27: U10.3 (QD); also elsewhere on the board
OM28: U10.4 (QE); also elsewhere on the board
OM29: U10.5 (QF); also elsewhere on the board
OM30: U10.6 (QG); also elsewhere on the board
OM31: U10.7 (QH); also elsewhere on the board
OM32: U11.15 (QA); also elsewhere on the board
OM33: U11.1 (QB); also elsewhere on the board
OM34: U11.2 (QC); also elsewhere on the board
OM35: U11.3 (QD); also elsewhere on the board
OM36: U11.4 (QE); also elsewhere on the board
OM37: U11.5 (QF); also elsewhere on the board
OM38: U11.6 (QG); also elsewhere on the board
OM39: U11.7 (QH); also elsewhere on the board
OM40: U12.15 (QA); also elsewhere on the board
OM41: U12.1 (QB); also elsewhere on the board
OM42: U12.2 (QC); also elsewhere on the board
OM43: U12.3 (QD); also elsewhere on the board
OM44: U12.4 (QE); also elsewhere on the board
OM45: U12.5 (QF); also elsewhere on the board
OM46: U12.6 (QG); also elsewhere on the board
OM47: U12.7 (QH); also elsewhere on the board
OM48: U13.15 (QA); also elsewhere on the board
OM49: U13.1 (QB); also elsewhere on the board
OM50: U13.2 (QC); also elsewhere on the board
OM51: U13.3 (QD); also elsewhere on the board
OM52: U13.4 (QE); also elsewhere on the board
OM53: U13.5 (QF); also elsewhere on the board
OM54: U13.6 (QG); also elsewhere on the board
OM55: U13.7 (QH); also elsewhere on the board
OM56: U14.15 (QA); also elsewhere on the board
OM57: U14.1 (QB); also elsewhere on the board
OM58: U14.2 (QC); also elsewhere on the board
OM59: U14.3 (QD); also elsewhere on the board
SERIAL_H2M: U7.14 (SER); also elsewhere on the board
SERIAL_MINUTE: U10.9 (QH'), U11.14 (SER)
SHIFT_CLEAR: U7.10 (~SRCLR), U8.10 (~SRCLR), U9.10 (~SRCLR), U10.10 (~SRCLR), U11.10 (~SRCLR), U12.10 (~SRCLR), U13.10 (~SRCLR), U14.10 (~SRCLR); also elsewhere on the board
SHIFT_OUTPUT: U7.13 (~OE), U8.13 (~OE), U9.13 (~OE), U10.13 (~OE), U11.13 (~OE), U12.13 (~OE), U13.13 (~OE), U14.13 (~OE); also elsewhere on the board
SPI_MISO: U14.9 (QH'); also elsewhere on the board
SPI_SCK: U7.11 (SRCLK), U8.11 (SRCLK), U9.11 (SRCLK), U10.11 (SRCLK), U11.11 (SRCLK), U12.11 (SRCLK), U13.11 (SRCLK), U14.11 (SRCLK); also elsewhere on the board
SPI_SS: U7.12 (RCLK), U8.12 (RCLK), U9.12 (RCLK), U10.12 (RCLK), U11.12 (RCLK), U12.12 (RCLK), U13.12 (RCLK), U14.12 (RCLK); also elsewhere on the board
VCC: C18.1, C19.1, C20.1, C21.1, C23.1, C25.1, C27.1, C29.1, U7.16 (VCC), U8.16 (VCC), U9.16 (VCC), U10.16 (VCC), U11.16 (VCC), U12.16 (VCC), U13.16 (VCC), U14.16 (VCC); also elsewhere on the board

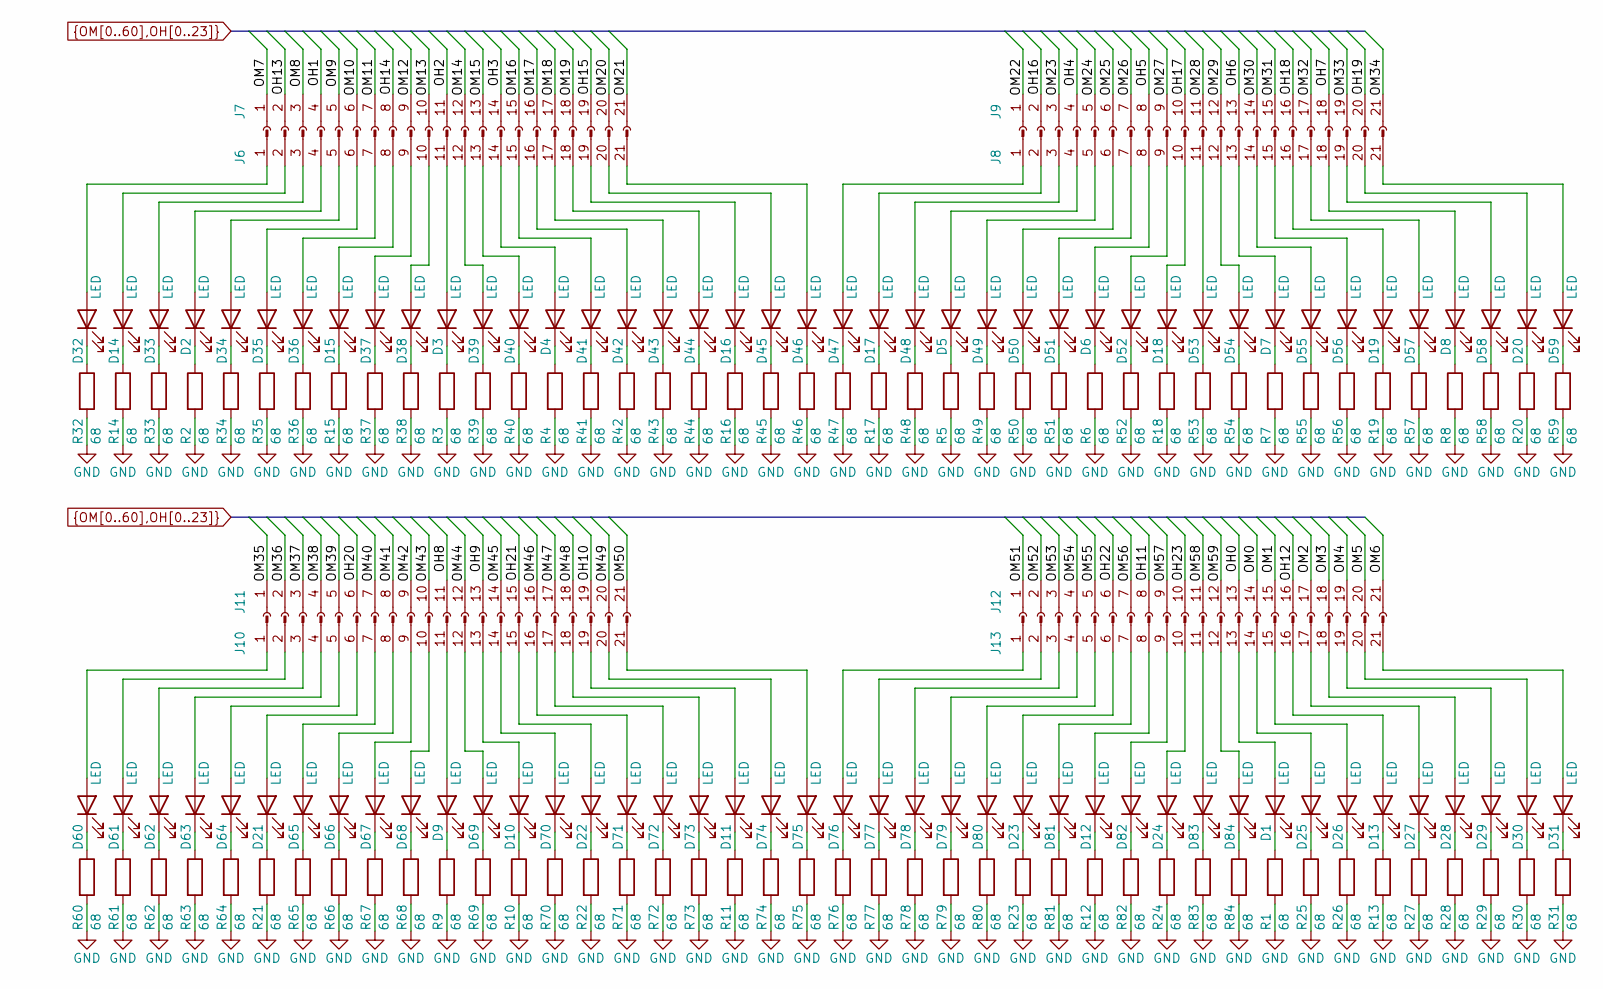
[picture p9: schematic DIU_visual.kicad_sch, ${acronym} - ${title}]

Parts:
D1, D2, D3, D4, D5, D6, D7, D8, D9, D10, D11, D12, D13, D14, D15, D16, D17, D18, D19, D20, D21, D22, D23, D24, D25, D26, D27, D28, D29, D30, D31, D32, D33, D34, D35, D36, D37, D38, D39, D40, D41, D42, D43, D44, D45, D46, D47, D48, D49, D50, D51, D52, D53, D54, D55, D56, D57, D58, D59, D60, D61, D62, D63, D64, D65, D66, D67, D68, D69, D70, D71, D72, D73, D74, D75, D76, D77, D78, D79, D80, D81, D82, D83, D84: LED; LED_1206_3216Metric
J6, J8, J10, J13: Conn_01x21_Pin; PinHeader_1x21_P2.54mm_Vertical
J7, J9, J11, J12: Conn_01x21_Socket; PinSocket_1x21_P2.54mm_Vertical
R1, R2, R3, R4, R5, R6, R7, R8, R9, R10, R11, R12, R13, R14, R15, R16, R17, R18, R19, R20, R21, R22, R23, R24, R25, R26, R27, R28, R29, R30, R31, R32, R33, R34, R35, R36, R37, R38, R39, R40, R41, R42, R43, R44, R45, R46, R47, R48, R49, R50, R51, R52, R53, R54, R55, R56, R57, R58, R59, R60, R61, R62, R63, R64, R65, R66, R67, R68, R69, R70, R71, R72, R73, R74, R75, R76, R77, R78, R79, R80, R81, R82, R83, R84: 68; R_1206_3216Metric

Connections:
GND: R1.2, R2.2, R3.2, R4.2, R5.2, R6.2, R7.2, R8.2, R9.2, R10.2, R11.2, R12.2, R13.2, R14.2, R15.2, R16.2, R17.2, R18.2, R19.2, R20.2, R21.2, R22.2, R23.2, R24.2, R25.2, R26.2, R27.2, R28.2, R29.2, R30.2, R31.2, R32.2, R33.2, R34.2, R35.2, R36.2, R37.2, R38.2, R39.2, R40.2, R41.2, R42.2, R43.2, R44.2, R45.2, R46.2, R47.2, R48.2, R49.2, R50.2, R51.2, R52.2, R53.2, R54.2, R55.2, R56.2, R57.2, R58.2, R59.2, R60.2, R61.2, R62.2, R63.2, R64.2, R65.2, R66.2, R67.2, R68.2, R69.2, R70.2, R71.2, R72.2, R73.2, R74.2, R75.2, R76.2, R77.2, R78.2, R79.2, R80.2, R81.2, R82.2, R83.2, R84.2; also elsewhere on the board
unnamed: D1.2 (A), J13.13
unnamed: D1.1 (K), R1.1
unnamed: D2.2 (A), J6.4
unnamed: D2.1 (K), R2.1
unnamed: D3.2 (A), J6.11
unnamed: D3.1 (K), R3.1
unnamed: D4.2 (A), J6.14
unnamed: D4.1 (K), R4.1
unnamed: D5.2 (A), J8.4
unnamed: D5.1 (K), R5.1
unnamed: D6.2 (A), J8.8
unnamed: D6.1 (K), R6.1
unnamed: D7.2 (A), J8.13
unnamed: D7.1 (K), R7.1
unnamed: D8.2 (A), J8.18
unnamed: D8.1 (K), R8.1
unnamed: D9.2 (A), J10.11
unnamed: D9.1 (K), R9.1
unnamed: D10.2 (A), J10.13
unnamed: D10.1 (K), R10.1
unnamed: D11.2 (A), J10.19
unnamed: D11.1 (K), R11.1
unnamed: D12.2 (A), J13.8
unnamed: D12.1 (K), R12.1
unnamed: D13.2 (A), J13.16
unnamed: D13.1 (K), R13.1
unnamed: D14.2 (A), J6.2
unnamed: D14.1 (K), R14.1
unnamed: D15.2 (A), J6.8
unnamed: D15.1 (K), R15.1
unnamed: D16.2 (A), J6.19
unnamed: D16.1 (K), R16.1
unnamed: D17.2 (A), J8.2
unnamed: D17.1 (K), R17.1
unnamed: D18.2 (A), J8.10
unnamed: D18.1 (K), R18.1
unnamed: D19.2 (A), J8.16
unnamed: D19.1 (K), R19.1
unnamed: D20.2 (A), J8.20
unnamed: D20.1 (K), R20.1
unnamed: D21.2 (A), J10.6
unnamed: D21.1 (K), R21.1
unnamed: D22.2 (A), J10.15
unnamed: D22.1 (K), R22.1
unnamed: D23.2 (A), J13.6
unnamed: D23.1 (K), R23.1
unnamed: D24.2 (A), J13.10
unnamed: D24.1 (K), R24.1
unnamed: D25.2 (A), J13.14
unnamed: D25.1 (K), R25.1
unnamed: D26.2 (A), J13.15
unnamed: D26.1 (K), R26.1
unnamed: D27.2 (A), J13.17
unnamed: D27.1 (K), R27.1
unnamed: D28.2 (A), J13.18
unnamed: D28.1 (K), R28.1
unnamed: D29.2 (A), J13.19
unnamed: D29.1 (K), R29.1
unnamed: D30.2 (A), J13.20
unnamed: D30.1 (K), R30.1
unnamed: D31.2 (A), J13.21
unnamed: D31.1 (K), R31.1
unnamed: D32.2 (A), J6.1
unnamed: D32.1 (K), R32.1
unnamed: D33.2 (A), J6.3
unnamed: D33.1 (K), R33.1
unnamed: D34.2 (A), J6.5
unnamed: D34.1 (K), R34.1
unnamed: D35.2 (A), J6.6
unnamed: D35.1 (K), R35.1
unnamed: D36.2 (A), J6.7
unnamed: D36.1 (K), R36.1
unnamed: D37.2 (A), J6.9
unnamed: D37.1 (K), R37.1
unnamed: D38.2 (A), J6.10
unnamed: D38.1 (K), R38.1
unnamed: D39.2 (A), J6.12
unnamed: D39.1 (K), R39.1
unnamed: D40.2 (A), J6.13
unnamed: D40.1 (K), R40.1
unnamed: D41.2 (A), J6.15
unnamed: D41.1 (K), R41.1
unnamed: D42.2 (A), J6.16
unnamed: D42.1 (K), R42.1
unnamed: D43.2 (A), J6.17
unnamed: D43.1 (K), R43.1
unnamed: D44.2 (A), J6.18
unnamed: D44.1 (K), R44.1
unnamed: D45.2 (A), J6.20
unnamed: D45.1 (K), R45.1
unnamed: D46.2 (A), J6.21
unnamed: D46.1 (K), R46.1
unnamed: D47.2 (A), J8.1
unnamed: D47.1 (K), R47.1
unnamed: D48.2 (A), J8.3
unnamed: D48.1 (K), R48.1
unnamed: D49.2 (A), J8.5
unnamed: D49.1 (K), R49.1
unnamed: D50.2 (A), J8.6
unnamed: D50.1 (K), R50.1
unnamed: D51.2 (A), J8.7
unnamed: D51.1 (K), R51.1
unnamed: D52.2 (A), J8.9
unnamed: D52.1 (K), R52.1
unnamed: D53.2 (A), J8.11
unnamed: D53.1 (K), R53.1
unnamed: D54.2 (A), J8.12
unnamed: D54.1 (K), R54.1
unnamed: D55.2 (A), J8.14
unnamed: D55.1 (K), R55.1
unnamed: D56.2 (A), J8.15
unnamed: D56.1 (K), R56.1
unnamed: D57.2 (A), J8.17
unnamed: D57.1 (K), R57.1
unnamed: D58.2 (A), J8.19
unnamed: D58.1 (K), R58.1
unnamed: D59.2 (A), J8.21
unnamed: D59.1 (K), R59.1
unnamed: D60.2 (A), J10.1
unnamed: D60.1 (K), R60.1
unnamed: D61.2 (A), J10.2
unnamed: D61.1 (K), R61.1
unnamed: D62.2 (A), J10.3
unnamed: D62.1 (K), R62.1
unnamed: D63.2 (A), J10.4
unnamed: D63.1 (K), R63.1
unnamed: D64.2 (A), J10.5
unnamed: D64.1 (K), R64.1
unnamed: D65.2 (A), J10.7
unnamed: D65.1 (K), R65.1
unnamed: D66.2 (A), J10.8
unnamed: D66.1 (K), R66.1
unnamed: D67.2 (A), J10.9
unnamed: D67.1 (K), R67.1
unnamed: D68.2 (A), J10.10
unnamed: D68.1 (K), R68.1
unnamed: D69.2 (A), J10.12
unnamed: D69.1 (K), R69.1
unnamed: D70.2 (A), J10.14
unnamed: D70.1 (K), R70.1
unnamed: D71.2 (A), J10.16
unnamed: D71.1 (K), R71.1
unnamed: D72.2 (A), J10.17
unnamed: D72.1 (K), R72.1
unnamed: D73.2 (A), J10.18
unnamed: D73.1 (K), R73.1
unnamed: D74.2 (A), J10.20
unnamed: D74.1 (K), R74.1
unnamed: D75.2 (A), J10.21
unnamed: D75.1 (K), R75.1
unnamed: D76.2 (A), J13.1
unnamed: D76.1 (K), R76.1
unnamed: D77.2 (A), J13.2
unnamed: D77.1 (K), R77.1
unnamed: D78.2 (A), J13.3
unnamed: D78.1 (K), R78.1
unnamed: D79.2 (A), J13.4
unnamed: D79.1 (K), R79.1
unnamed: D80.2 (A), J13.5
unnamed: D80.1 (K), R80.1
unnamed: D81.2 (A), J13.7
unnamed: D81.1 (K), R81.1
unnamed: D82.2 (A), J13.9
unnamed: D82.1 (K), R82.1
unnamed: D83.2 (A), J13.11
unnamed: D83.1 (K), R83.1
unnamed: D84.2 (A), J13.12
unnamed: D84.1 (K), R84.1
OH0: J12.13; also elsewhere on the board
OH1: J7.4; also elsewhere on the board
OH2: J7.11; also elsewhere on the board
OH3: J7.14; also elsewhere on the board
OH4: J9.4; also elsewhere on the board
OH5: J9.8; also elsewhere on the board
OH6: J9.13; also elsewhere on the board
OH7: J9.18; also elsewhere on the board
OH8: J11.11; also elsewhere on the board
OH9: J11.13; also elsewhere on the board
OH10: J11.19; also elsewhere on the board
OH11: J12.8; also elsewhere on the board
OH12: J12.16; also elsewhere on the board
OH13: J7.2; also elsewhere on the board
OH14: J7.8; also elsewhere on the board
OH15: J7.19; also elsewhere on the board
OH16: J9.2; also elsewhere on the board
OH17: J9.10; also elsewhere on the board
OH18: J9.16; also elsewhere on the board
OH19: J9.20; also elsewhere on the board
OH20: J11.6; also elsewhere on the board
OH21: J11.15; also elsewhere on the board
OH22: J12.6; also elsewhere on the board
OH23: J12.10; also elsewhere on the board
OM0: J12.14; also elsewhere on the board
OM1: J12.15; also elsewhere on the board
OM2: J12.17; also elsewhere on the board
OM3: J12.18; also elsewhere on the board
OM4: J12.19; also elsewhere on the board
OM5: J12.20; also elsewhere on the board
OM6: J12.21; also elsewhere on the board
OM7: J7.1; also elsewhere on the board
OM8: J7.3; also elsewhere on the board
OM9: J7.5; also elsewhere on the board
OM10: J7.6; also elsewhere on the board
OM11: J7.7; also elsewhere on the board
OM12: J7.9; also elsewhere on the board
OM13: J7.10; also elsewhere on the board
OM14: J7.12; also elsewhere on the board
OM15: J7.13; also elsewhere on the board
OM16: J7.15; also elsewhere on the board
OM17: J7.16; also elsewhere on the board
OM18: J7.17; also elsewhere on the board
OM19: J7.18; also elsewhere on the board
OM20: J7.20; also elsewhere on the board
OM21: J7.21; also elsewhere on the board
OM22: J9.1; also elsewhere on the board
OM23: J9.3; also elsewhere on the board
OM24: J9.5; also elsewhere on the board
OM25: J9.6; also elsewhere on the board
OM26: J9.7; also elsewhere on the board
OM27: J9.9; also elsewhere on the board
OM28: J9.11; also elsewhere on the board
OM29: J9.12; also elsewhere on the board
OM30: J9.14; also elsewhere on the board
OM31: J9.15; also elsewhere on the board
OM32: J9.17; also elsewhere on the board
OM33: J9.19; also elsewhere on the board
OM34: J9.21; also elsewhere on the board
OM35: J11.1; also elsewhere on the board
OM36: J11.2; also elsewhere on the board
OM37: J11.3; also elsewhere on the board
OM38: J11.4; also elsewhere on the board
OM39: J11.5; also elsewhere on the board
OM40: J11.7; also elsewhere on the board
OM41: J11.8; also elsewhere on the board
OM42: J11.9; also elsewhere on the board
OM43: J11.10; also elsewhere on the board
OM44: J11.12; also elsewhere on the board
OM45: J11.14; also elsewhere on the board
OM46: J11.16; also elsewhere on the board
OM47: J11.17; also elsewhere on the board
OM48: J11.18; also elsewhere on the board
OM49: J11.20; also elsewhere on the board
OM50: J11.21; also elsewhere on the board
OM51: J12.1; also elsewhere on the board
OM52: J12.2; also elsewhere on the board
OM53: J12.3; also elsewhere on the board
OM54: J12.4; also elsewhere on the board
OM55: J12.5; also elsewhere on the board
OM56: J12.7; also elsewhere on the board
OM57: J12.9; also elsewhere on the board
OM58: J12.11; also elsewhere on the board
OM59: J12.12; also elsewhere on the board

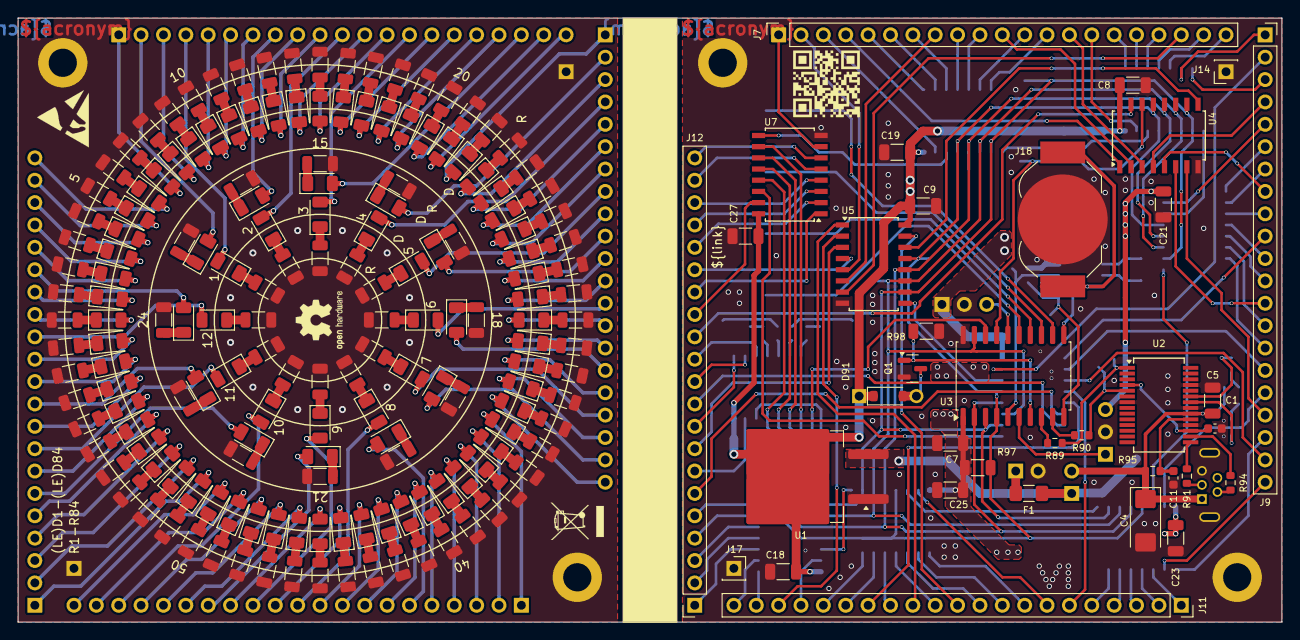
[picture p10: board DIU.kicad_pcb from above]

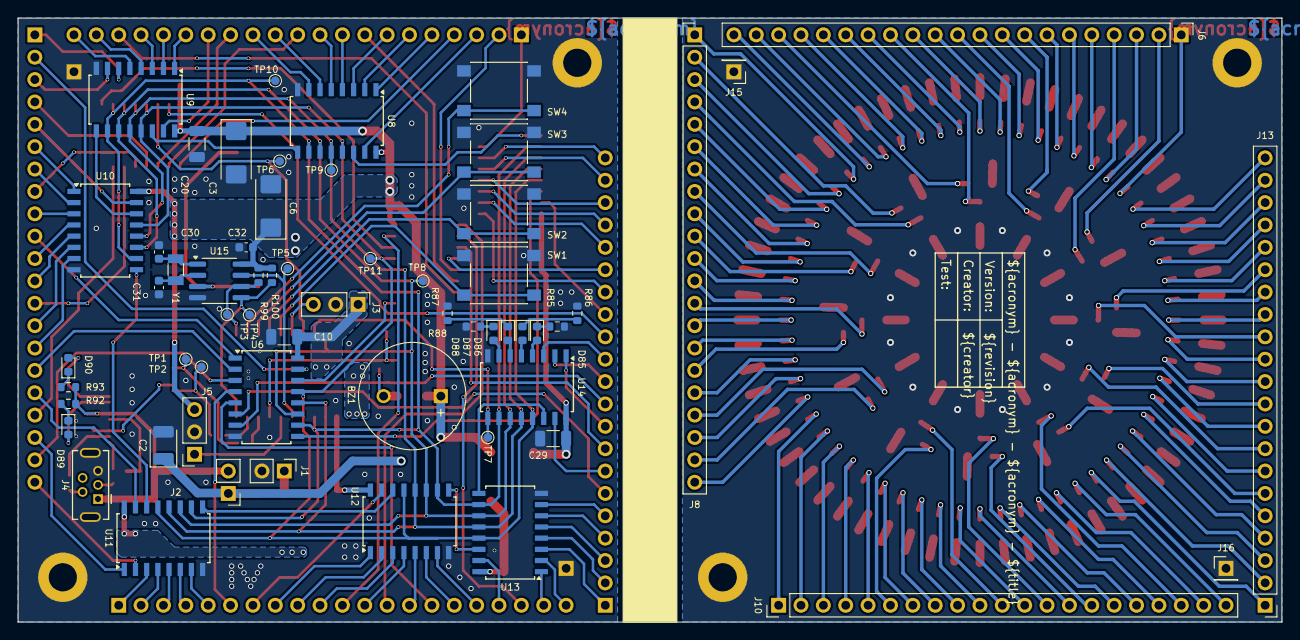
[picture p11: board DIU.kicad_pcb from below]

Board: 2 copper layers, 143.5 x 68.6 mm, 272 parts (60 on the bottom side), 309 nets.

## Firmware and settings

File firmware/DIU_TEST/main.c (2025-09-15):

#include "main.h"

static char repeat_text[] = "Repeat test [y/n]: ";
volatile unsigned char second;

ISR(PORTA_PORT_vect)
{
	second++;
	EXTERNAL_INTERRUPT_TRIGGER_PORT.INTFLAGS = EXTERNAL_INTERRUPT_TRIGGER_PIN;
}

ISR(TCA0_OVF_vect)
{
	TCA0.SINGLE.INTFLAGS = TCA_SINGLE_OVF_bm;
}

ISR(TCA0_CMP0_vect)
{
	TCA0.SINGLE.INTFLAGS = TCA_SINGLE_CMP0_bm;
}

ISR(TCB0_INT_vect)
{
	PORTB.OUTTGL = PIN4_bm;
	
	TCB0.INTFLAGS = TCB_CAPT_bm;
}

static unsigned char confirm(void)
{
	unsigned char repeat = '\0';
	
	do
	{
		printf("%s", repeat_text);
		scanf("%c", &repeat);
		printf("\n\r");
		
	} while (repeat != 'y' && repeat != 'n');
	
	printf("\n\r");
	
	if(repeat == 'n')
	{
		return 0;
	}
	return 1;
}

static void counter_init(void)
{
	TCB0.CCMP = 0x1387;
	TCB0.INTCTRL = TCB_CAPT_bm;
	TCB0.CTRLB = TCB_CNTMODE_INT_gc;
	TCB0.CTRLA = TCB_CLKSEL_CLKDIV2_gc | TCB_ENABLE_bm;
	sei();
}

static void counter_disable(void)
{
	TCA0.SINGLE.CTRLA &= ~(TCA_SINGLE_CLKSEL_DIV8_gc | TCA_SINGLE_ENABLE_bm);
}

int main(void)
{
	EXTERNAL_INTERRUPT_TRIGGER_PORT.DIRCLR = EXTERNAL_INTERRUPT_TRIGGER_PIN;
	EXTERNAL_INTERRUPT_TRIGGER_PORT.EXTERNAL_INTERRUPT_TRIGGER_PINCTRL = EXTERNAL_INTERRUPT_TRIGGER_PIN_SETUP;
	
	system_init();
	
	sei();
	
	input_init();
	uart_init();
	mcp7940_init(RTC_Enable);
	clock_init();
	clock_setdata(0UL, 0UL, CLOCK_LED_None);
	
	printf("\n\n\n\rStarting System Test:\n\n\r");
	
	do 
	{
		printf("1.) Button:\n\n\r");
		
		for (unsigned char i=0; i < 4; i++)
		{
			printf("    -> Press S%1u: ", (i + 1));
			while (input_status((1<<i)) == OFF);
			printf("Push detected!\n\r");
		}
		printf("\n\r");
		
	} while (confirm());
	
	do
	{
		printf("2.) Running LED Test:\n\n\r");
		
		for (unsigned char i=0; i < 24; i++)
		{
			clock_settime(i, 0, 0, CLOCK_LED_None);
			printf("    -> Hour: %2u\r", i);
			_delay_ms(250);
		}
		printf("\n\r");
		
		for (unsigned char i=0; i < 60; i++)
		{
			clock_settime(0, i, 0, CLOCK_LED_None);
			printf("    -> Minute: %2u\r", i);
			_delay_ms(250);
		}
		printf("\n\r");
		
		for (unsigned char i=0; i < 4; i++)
		{
			clock_settime(0, 0, 0, (1<<i));
			printf("    -> Clock Back-LEDS: %2u\r", (i + 1));
			_delay_ms(2000);
		}
		printf("\n\n\r");
		
	} while (confirm());
	
	do
	{
		printf("2.) Running Buzzer Test:\n\n\r");
		
		PORTB.DIRSET = PIN4_bm;
		PORTB.OUTCLR = PIN4_bm;
		counter_init();
		
		_delay_ms(5000);
		
		counter_disable();
		PORTB.DIRCLR = PIN4_bm;
		PORTB.OUTCLR = PIN4_bm;
		
		printf("    -> Done\r\n\n");
		
	} while (confirm());
	
	unsigned char fault = 0;
	
	do
	{
		printf("3.) Running RTC Test:\n\n\r");
		printf("    -> Resetting\n\r");
		second = 0;
		
		for (unsigned char i=0; i < 10; i++)
		{
			printf("    -> Wait for trigger: %2u\r", (10 - i));
			_delay_ms(1200);
		}
		
		if (second > 9)
		{
			printf("    -> Trigger confirmed (%u)\n\r", second);
			printf("    -> Real Time Clock running\n\r");
		}
		else
		{
			printf("    -> Trigger not found (%u)\n\r", second);
			printf("    -> Real Time Clock error\n\r");
			
			fault = 1;
		}
		printf("\n\r");
		
	} while (confirm());
	
	if(fault)
	{
		printf("\n\n\rSystem test failure, check system status!\n\r");
	}
	else
	{
		printf("\n\n\rSystem test successful, everything is running!\n\r");
	}
	
    while (1) 
    {
    }
}

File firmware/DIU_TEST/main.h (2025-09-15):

#ifndef MAIN_H_
#define MAIN_H_

	#ifndef F_CPU
		#define F_CPU 20000000UL
	#endif
	
    #ifndef EXTERNAL_INTERRUPT_TRIGGER_PORT
        #define EXTERNAL_INTERRUPT_TRIGGER_PORT PORTA
    #endif

    #ifndef EXTERNAL_INTERRUPT_TRIGGER_PIN
        #define EXTERNAL_INTERRUPT_TRIGGER_PIN       PIN7_bm
        #define EXTERNAL_INTERRUPT_TRIGGER_PINCTRL   PIN7CTRL
        #define EXTERNAL_INTERRUPT_TRIGGER_PIN_SETUP PORT_ISC_FALLING_gc | PORT_PULLUPEN_bm
    #endif

    #include <avr/io.h>
    #include <avr/interrupt.h>
    #include <util/delay.h>

    #include "../lib/system/system.h"
    #include "../lib/input/input.h"
    #include "../lib/uart/uart.h"
    #include "../lib/clock/clock.h"
    #include "../lib/rtc/mcp7940.h"

#endif /* MAIN_H_ */

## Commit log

2025-09-13 Partlist refactoring
    [DIU.kicad_sch, DIU_hour.kicad_sch, DIU_minute.kicad_sch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]
2025-09-13 Change reset circuit
    [DIU.kicad_pcb, DIU.kicad_sch]
2025-09-13 Fix footprint reference match problem
    [DIU.kicad_pcb]
2025-09-13 Change silkscreen text size
    [DIU.kicad_pcb]
2025-09-13 Add missing 3d models
    [DIU.kicad_pcb]
2025-09-13 Add value to BOM
2025-09-14 Add resistor to reset circuit
    [DIU.kicad_pcb, DIU.kicad_sch]
2025-09-14 Rearrange text on fabrication layer
    [DIU.kicad_pcb]
2025-10-16 Extend exploded assembly
    [housing.FCStd]
2026-01-28 Fix wrong led polarity
2026-01-28 Adapt vendor-ids on leds

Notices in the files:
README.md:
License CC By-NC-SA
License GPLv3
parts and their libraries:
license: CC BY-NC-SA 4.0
